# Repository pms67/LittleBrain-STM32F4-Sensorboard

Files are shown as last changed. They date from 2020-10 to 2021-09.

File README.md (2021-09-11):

# LittleBrain-STM32F4-Sensorboard
STM32F4-based PCB interfacing with a variety of sensors.

- Learn how to design your own STM32-based PCB ([https://youtu.be/x_5rYfAyqq0](https://youtu.be/x_5rYfAyqq0))!
- Learn how to write firmware for the STM32 microcontroller ([https://youtu.be/C7-8nUU6e3E](https://youtu.be/C7-8nUU6e3E))!

You can order this board (incl. SMT assembly) at [https://www.jlcpcb.com/RPH](https://www.jlcpcb.com/RPH). Gerber and assembly files are in the relevant repo folders.

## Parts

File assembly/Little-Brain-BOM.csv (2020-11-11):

Comment | Designator | Footprint | LCSC
10u | C100,C102,C103 | Capacitor_SMD:C_1206_3216Metric | C13585
10n | C101 | Capacitor_SMD:C_0603_1608Metric | C57112
4u7 | C200 | Capacitor_SMD:C_0603_1608Metric | C19666
1u | C206 | Capacitor_SMD:C_0402_1005Metric | C52923
10n | C207 | Capacitor_SMD:C_0402_1005Metric | C15195
2u2 | C208,C209 | Capacitor_SMD:C_0603_1608Metric | C23630
12p | C210,C211 | Capacitor_SMD:C_0402_1005Metric | C1547
100n | C201,C202,C203,C204,C205,C212,C213,C300,C301,C302,C303,C400 | Capacitor_SMD:C_0402_1005Metric | C1525
B5819W | D100,D101 | Diode_SMD:D_SOD-123 | C8598
GREEN | D102 | LED_SMD:LED_0603_1608Metric | C72043
RED | D200 | LED_SMD:LED_0603_1608Metric | C2286
19-237/R6GHBHC-A01/2T | D201 | RGB_LED:19-237-R6GHBHC-A01-2T | C60105
250mA | F100 | Fuse:Fuse_1206_3216Metric | C70068
600 @ 600 MHz | FB100,FB200 | Inductor_SMD:L_0805_2012Metric | C1017
10u | L101 | Inductor_SMD:L_Sunlord_MWSA0518_5.4x5.2mm | C139506
AO3401A | Q100 | Package_TO_SOT_SMD:SOT-23 | C15127
100k | R100 | Resistor_SMD:R_0603_1608Metric | C25803
68k | R101 | Resistor_SMD:R_0603_1608Metric | C23231
47k | R102 | Resistor_SMD:R_0603_1608Metric | C25819
15k | R103 | Resistor_SMD:R_0603_1608Metric | C22809
270 | R104 | Resistor_SMD:R_0603_1608Metric | C22966
1k5 | R105 | Resistor_SMD:R_0603_1608Metric | C22843
47 | R200 | Resistor_SMD:R_0402_1005Metric | C25118
1k | R202 | Resistor_SMD:R_0603_1608Metric | C21190
2k2 | R204,R205 | Resistor_SMD:R_0402_1005Metric | C25879
1k | R206,R207,R208 | Resistor_SMD:R_0402_1005Metric | C11702
10k | R201,R203,R209,R210 | Resistor_SMD:R_0402_1005Metric | C25744
22 | R400,R401,R402,R403,R404,R405,R406,R407,R408,R409,R410,R411,R412,R413,R414,R415 | Resistor_SMD:R_0402_1005Metric | C25092
MP2359DJ-LF-Z | U100 | Package_TO_SOT_SMD:SOT-23-6 | C14259
STM32F405RGT6 | U200 | Package_QFP:LQFP-64_10x10mm_P0.5mm | C15742
W25N01GVZEIG | U201 | WinbondFlash:W25N01GVZEIG | C88868
BMP280 | U300 | Package_LGA:Bosch_LGA-8_2x2.5mm_P0.65mm_ClockwisePinNumbering | C233787
BMI088 | U301 | BMI088:BMI088 | C194919
16MHz | Y200 | Crystal:Crystal_SMD_3225-4Pin_3.2x2.5mm | C13738

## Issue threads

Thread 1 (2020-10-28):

Gerber

nbgsmk, 2020-10-28:
Hello friend!
I found your youtube video on stm32 and I thought, let's give it a try! I also wanted to see how it looks in jlcpcb's ordering tool, and to perfect the process, as I am not experienced with pcb fabs. But after uploading gerber files to jlcpcb (I used the provided .rar), the board dimensions are not detected (both fields are empty) and there is no board-preview, as usual. Therefore, the option of their smt assembly is not enabled. Do you know what could be the issue? Thanks!

pms67, 2020-10-28:
Hey there,
That's strange - I just tried uploading the files again myself and everything appears as it should.

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

Maybe some sort of browser issue?

nbgsmk, 2020-10-28:
Hello again!
You're right! Somehow. :)  Ofcourse, I tried twice in the morning, and twice again this evening. And this time it works. But it's the same browser as before. So I'm thinking maybe because I restarted Firefox due to update, or it was some issue on their site. No big deal...actually I learned it is worth waiting and trying, eg. on the following day. Thanks for your quick reply! You can close the issue.
Zoran

Closed 2020-11-07.

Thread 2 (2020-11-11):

W25N01 Spi Nand Flash

MrMehdi, 2020-11-11:
Hi bro
thnx for shareing your nice project.
please start working on w25n01 driver and file system.
that's very nice chip for storage big data
i have some problem for implement a file system like rl-flashfs for this chip.
i wrote a raw low-lever driver for this chip , if you need tell me for sharing to you
i waiting on you to complete this part of your project!
i hope you start very soon
thnx bro.

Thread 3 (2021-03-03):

MP2359 now end of life at JLCPCB

m1geo, 2021-03-03:
Just to let you know that the MP2359DJ-LF-Z is no longer stocked at JLCPCB or LCSC.
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

pms67, 2021-03-12:
Hi there, Thanks - I'm making an updated version of this board with different components. Will make a new video, once I have it in my hands. :)

Closed 2021-03-12.

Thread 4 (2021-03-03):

[Question] Parts designation numbers schema

bennymeg, 2021-03-03:
Hi,
I see you have assign a unique range of numbers for parts designators to each schematic page.
I assume the reason behind it is that it would be easy to understand to each function of the board each component relate to by simply looking at the silk screen. Nice trick!

 - Is that a common practice to do so? can please explain a bit about it?
 - Can you please explain how you did it in KiCad?

Thanks.

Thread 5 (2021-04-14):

U100/U200 no longer known to JLCPCB?

rpbgit, 2021-04-14:
Hi Phil,
wonderful vids on your youtube channel.  Really like your approach from pencil to practice and actual implementations.   particularly the filter/dsp stuff (new to me).   recently retired engineer and a couple of colleagues looking to simulate the brain cells again.  Just turned my first KiCAD boards (simple stuff) for a club built project to learn that.

trying to order some littebrain PCBs ordering from JLCPCB as you have noted in the vids.  However, U100/U100 are no longer known to JLCPCB.  any way to readily correct this?   Would like to follow along with your vids using the LB as the devboard as closely as possible.

Really like the STM32 stuff and recently ordered a STM32H743 Nucleo-144 board but haven't yet gotten the dev environment setup.   If the solution to ordering LittleBrain is longer term, we will probably just go with ordering some sort of BL088 module and get it working with a Nucleo-board.

any suggestions?

rpbgit, 2021-04-16:
ooops U200 and U100

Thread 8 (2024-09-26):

SPI NSS for gyro and accelerometer being pulled low at the same time.

jisang1213, 2024-09-26:
I've faced an issue with gyro and accelerometer CS pins being pulled low simultaneously, making the retrieved data contain garbage values once a while (about every 1~2 seconds). There needs to be a mechanism to prevent this like using while() to wait for its turn to read.
```
void HAL_GPIO_EXTI_Callback(uint16_t GPIO_Pin) {
	if (GPIO_Pin == INT_ACC_Pin) {
                while(imu.readingGyr);
                BMI088_ReadAccelerometerDMA(&imu);

	} else if (GPIO_Pin == INT_GYR_Pin) {
                while(imu.readingAcc);
                BMI088_ReadGyroscopeDMA(&imu);
	}
}
```
and in the BMI088.c file the imu.readingGyr and imu.readingAcc flags should be set before pulling the CS low (and unset after pulling CS to high) to prevent race condition.

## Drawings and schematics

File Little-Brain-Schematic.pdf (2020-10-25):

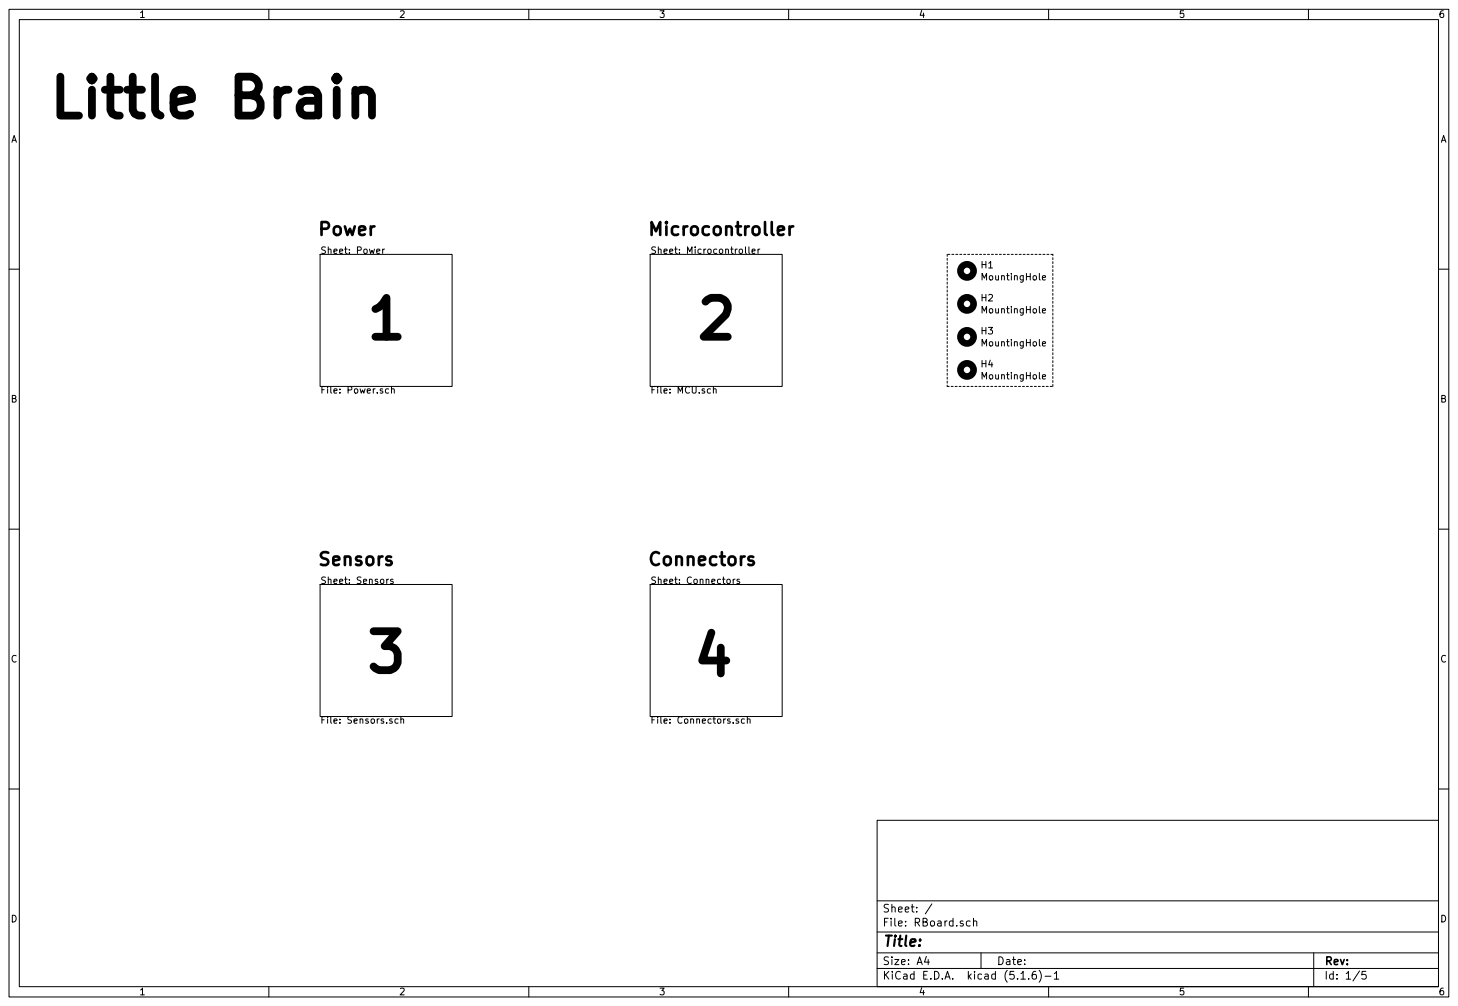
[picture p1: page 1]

Id: 1/5 Title: File: RBoard.sch Sheet: /

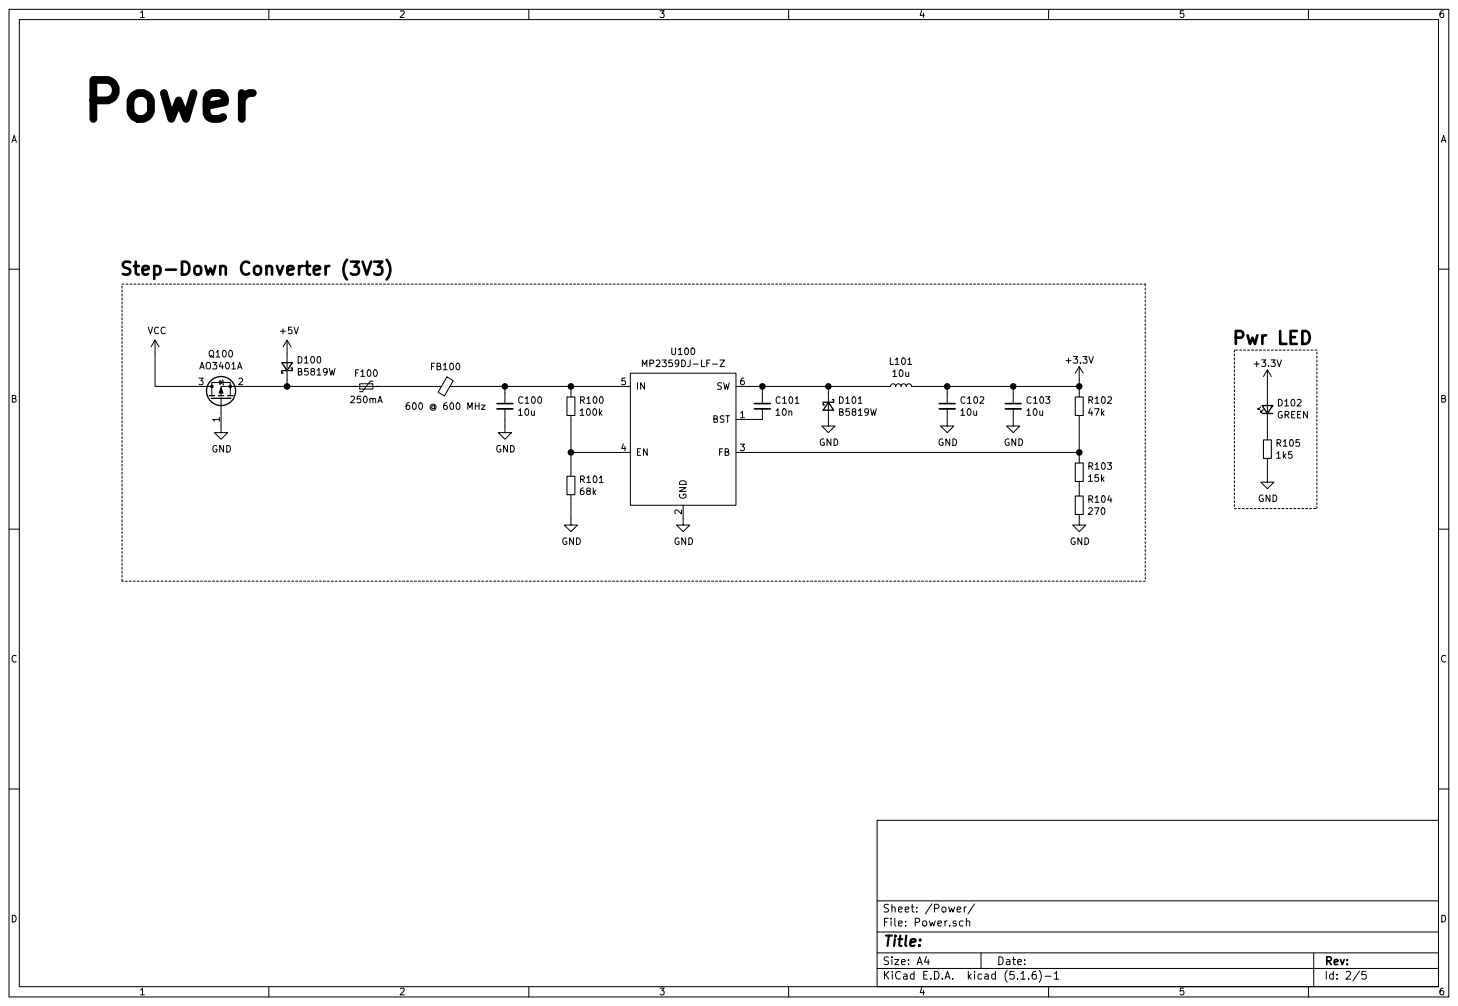
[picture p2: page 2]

Id: 2/5 Title: File: Power.sch Sheet: /Power/

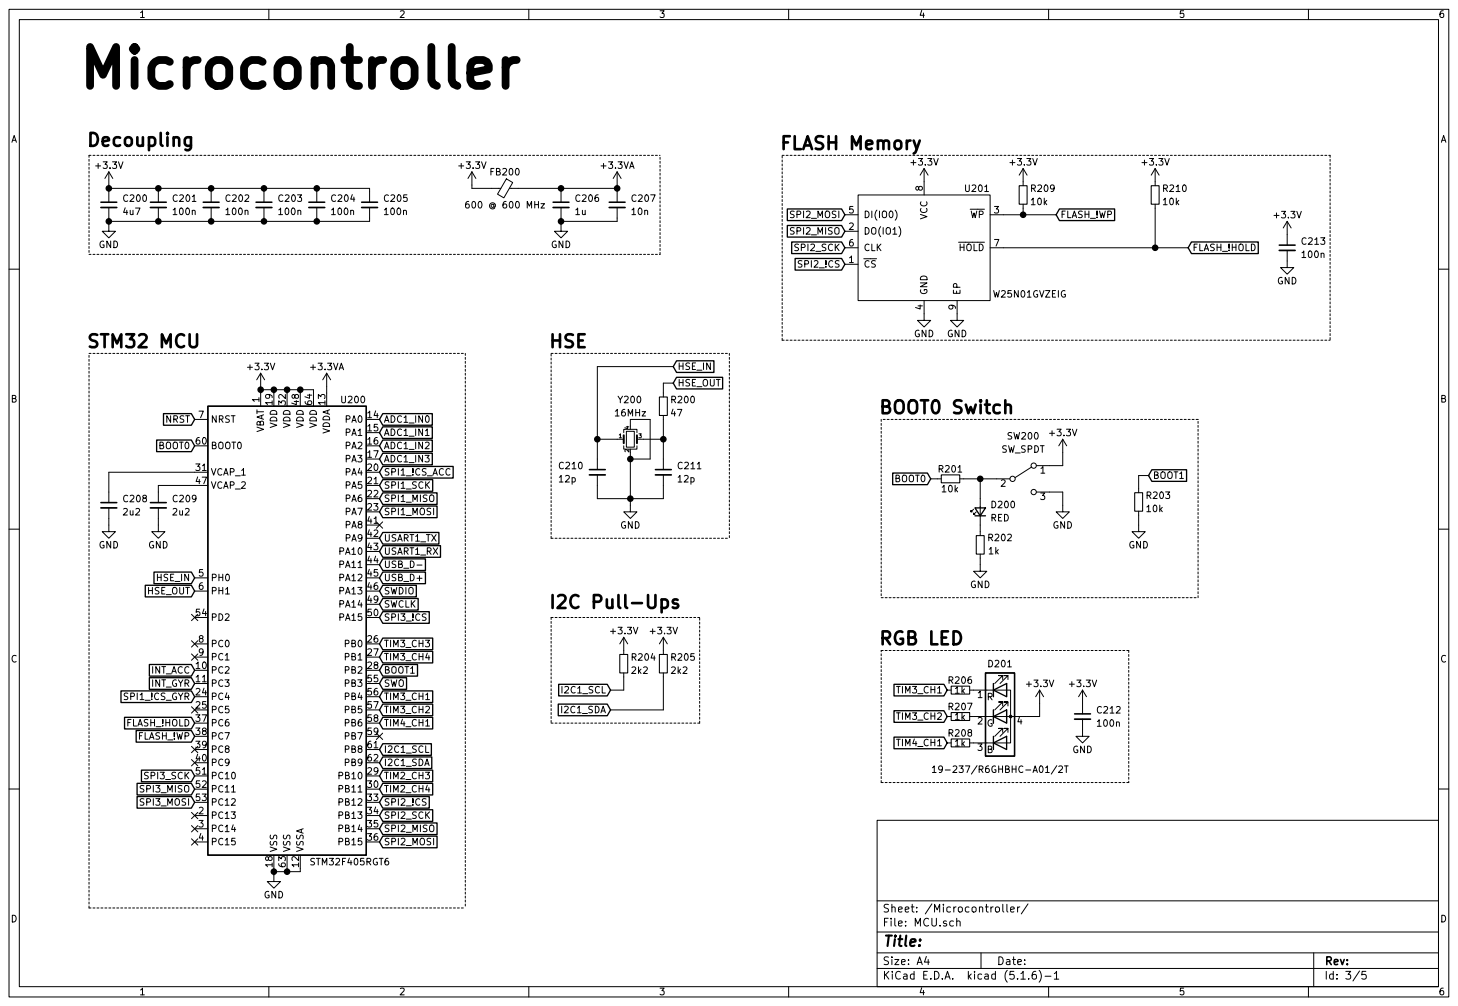
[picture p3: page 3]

4 DI(IO0) 5 CLK 6 HOLD 7 VCC

1 VCAP_1 31 VCAP_2 47 VDD 19 VDD 32 VDD 48 VDD 64 VDDA 13 VSS 18 VSS 63 VSSA 12 U200 STM32F405RGT6

Id: 3/5 Title: File: MCU.sch Sheet: /Microcontroller/ GND

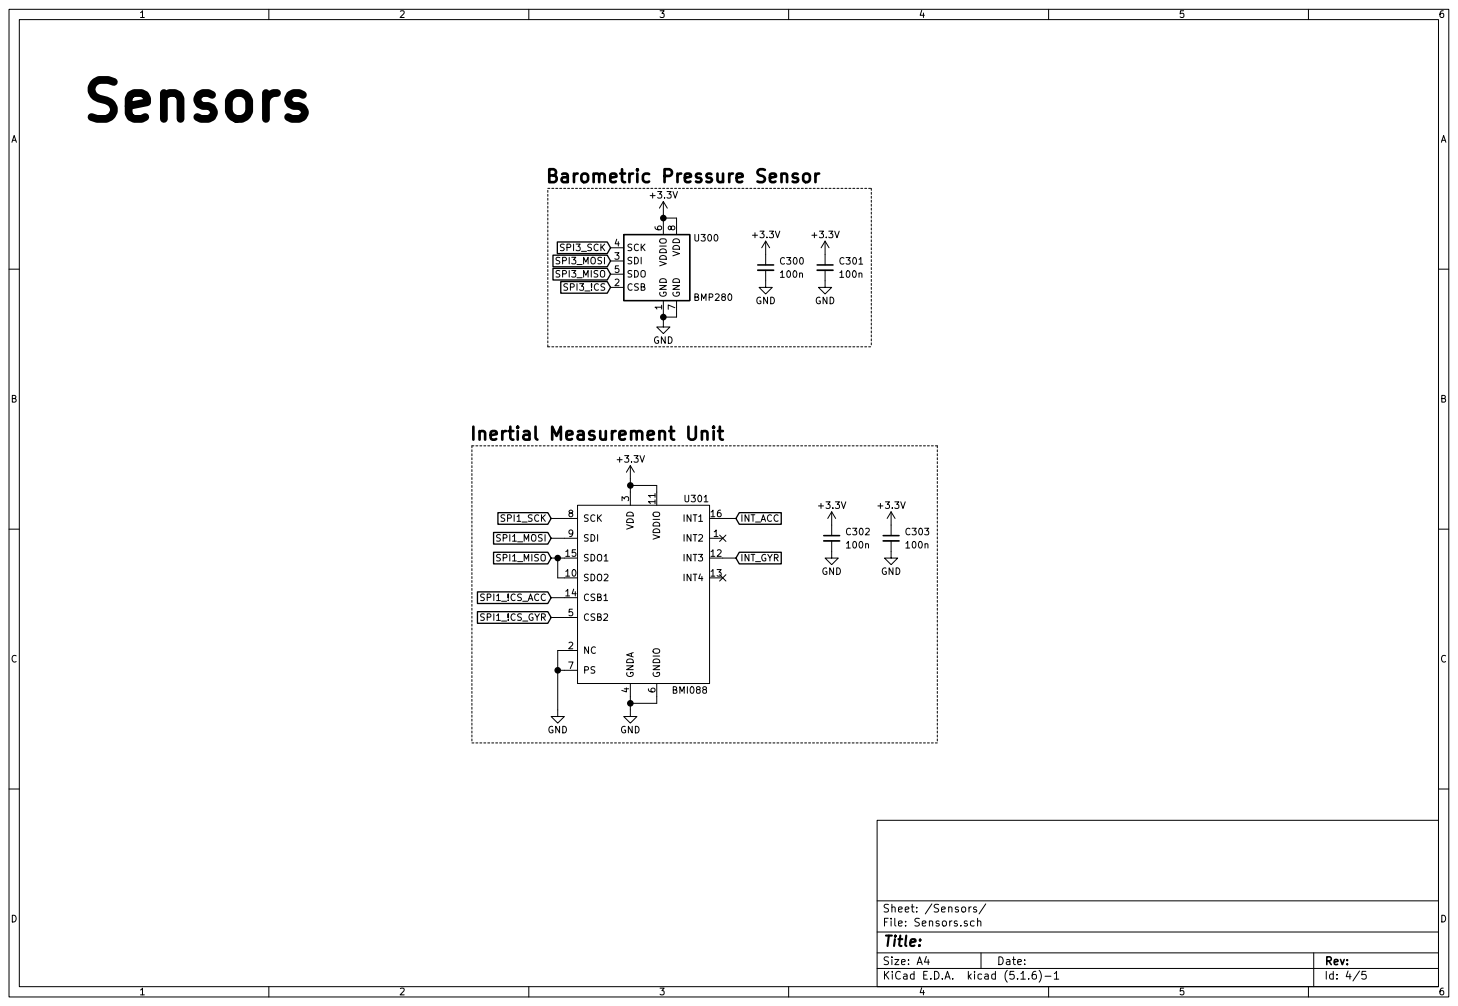
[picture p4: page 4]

1 CSB 2 SDI 3 SCK 4 SDO 5 VDDIO

6 PS 7 SCK 8 SDI 9 U301 BMI088 GND

Id: 4/5 Title: File: Sensors.sch Sheet: /Sensors/ C303

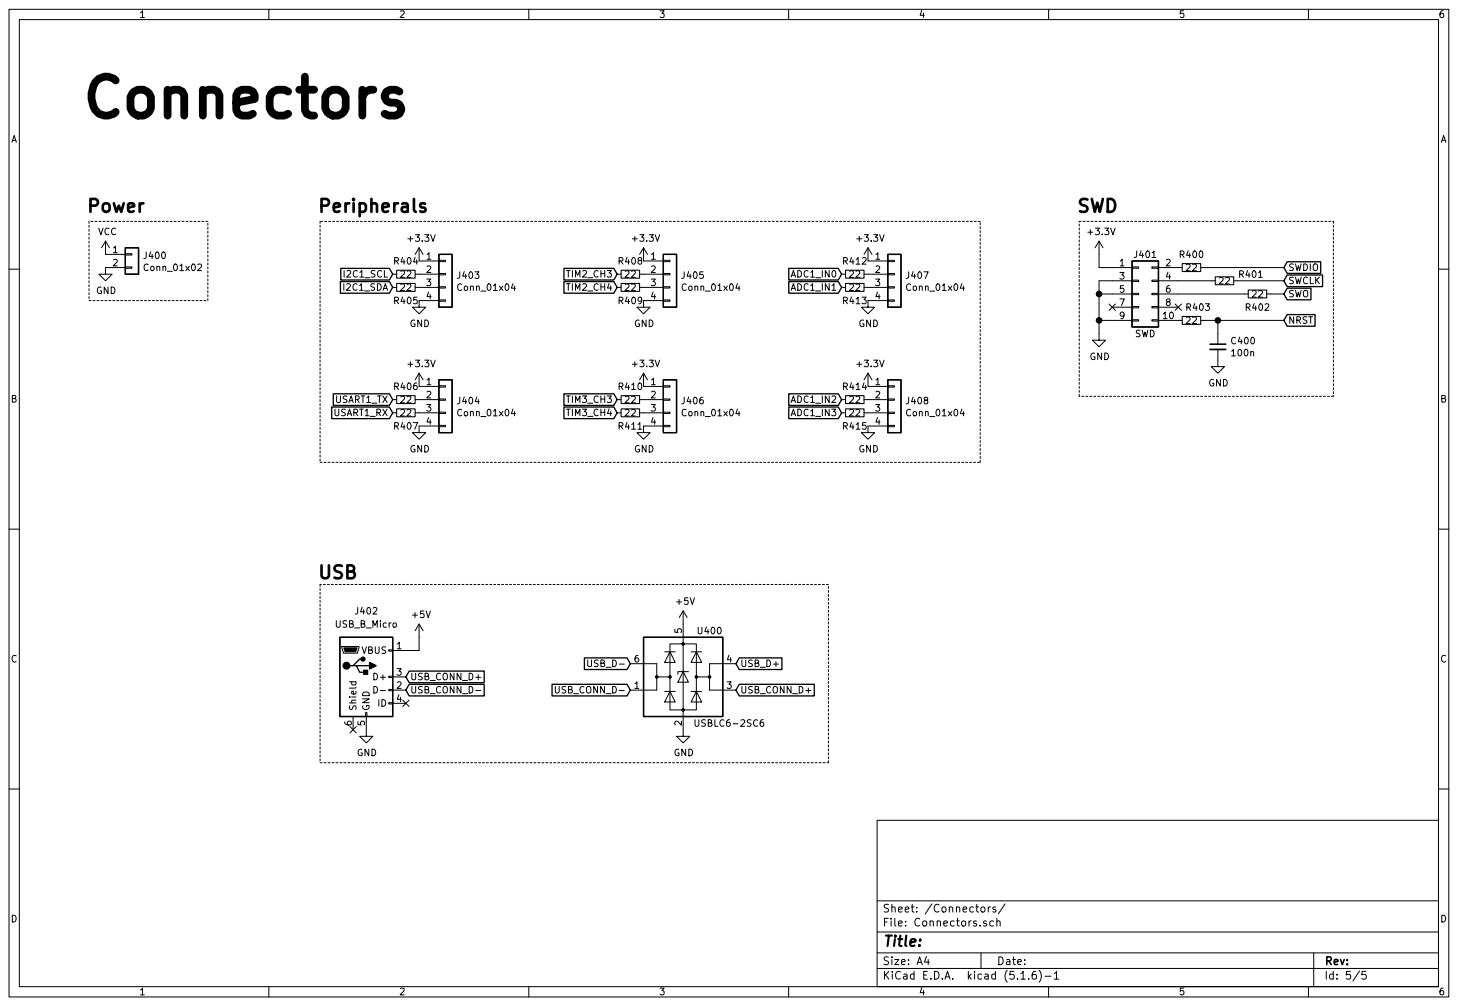
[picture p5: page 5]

Id: 5/5 Title: File: Connectors.sch Sheet: /Connectors/

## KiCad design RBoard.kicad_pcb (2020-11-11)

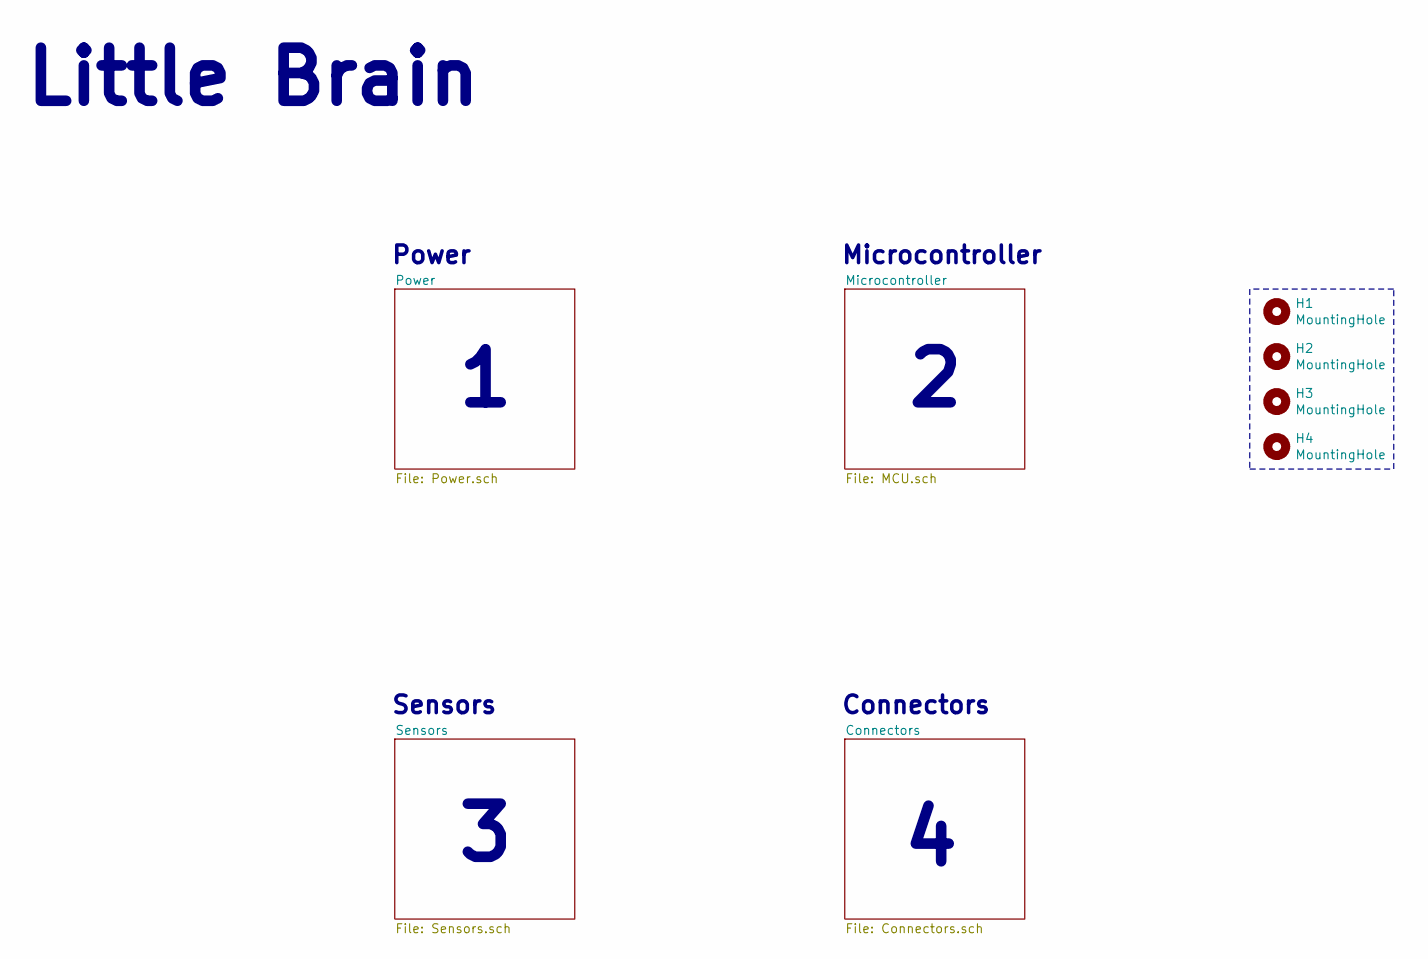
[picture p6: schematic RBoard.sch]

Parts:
H1, H2, H3, H4: MountingHole; MountingHole_3.2mm_M3

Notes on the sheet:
Little Brain
Power
Microcontroller
Sensors
Connectors

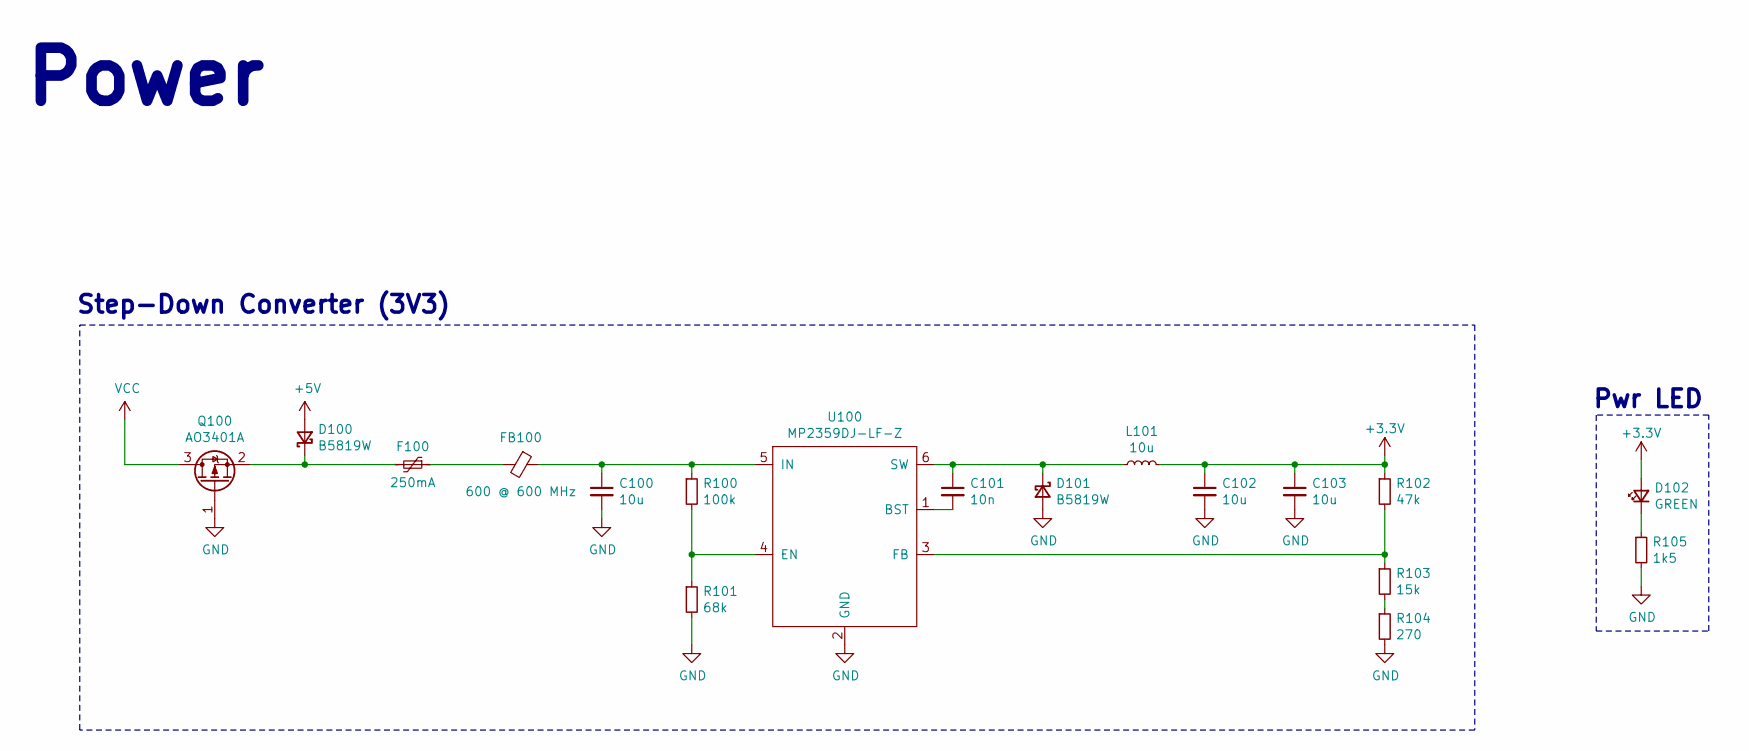
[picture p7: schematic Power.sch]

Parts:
C100, C102, C103: 10u; C_1206_3216Metric; LCSC Part # C13585
C101: 10n; C_0603_1608Metric; LCSC Part # C57112
D100, D101: B5819W; D_SOD-123; LCSC Part # C8598
D102: GREEN; LED_0603_1608Metric; LCSC Part # C72043
F100: 250mA; Fuse_1206_3216Metric; LCSC Part # C70068
FB100: 600 @ 600 MHz; L_0805_2012Metric; LCSC Part # C1017
L101: 10u; L_Sunlord_MWSA0518_5.4x5.2mm; LCSC Part # C139506
Q100: AO3401A; SOT-23; LCSC Part # C15127
R100: 100k; R_0603_1608Metric; LCSC Part # C25803
R101: 68k; R_0603_1608Metric; LCSC Part # C23231
R102: 47k; R_0603_1608Metric; LCSC Part # C25819
R103: 15k; R_0603_1608Metric; LCSC Part # C22809
R104: 270; R_0603_1608Metric; LCSC Part # C22966
R105: 1k5; R_0603_1608Metric; LCSC Part # C22843
U100: MP2359DJ-LF-Z; SOT-23-6; LCSC Part # C14259

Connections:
+3V3: C102.1, C103.1, D102.2 (A), L101.2, R102.1; also elsewhere on the board
+5V: D100.2 (A); also elsewhere on the board
GND: C100.2, C102.2, C103.2, D101.2 (A), Q100.1 (G), R101.2, R104.2, R105.2, U100.2 (GND); also elsewhere on the board
unnamed: C100.1, FB100.1, R100.1, U100.5 (IN)
unnamed: C101.1, D101.1 (K), L101.1, U100.6 (SW)
unnamed: C101.2, U100.1 (BST)
unnamed: D100.1 (K), F100.2, Q100.2 (S)
unnamed: D102.1 (K), R105.1
unnamed: F100.1, FB100.2
unnamed: R100.2, R101.1, U100.4 (EN)
unnamed: R102.2, R103.1, U100.3 (FB)
unnamed: R103.2, R104.1
VCC: Q100.3 (D); also elsewhere on the board

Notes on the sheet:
Power
Step-Down Converter (3V3)
Pwr LED

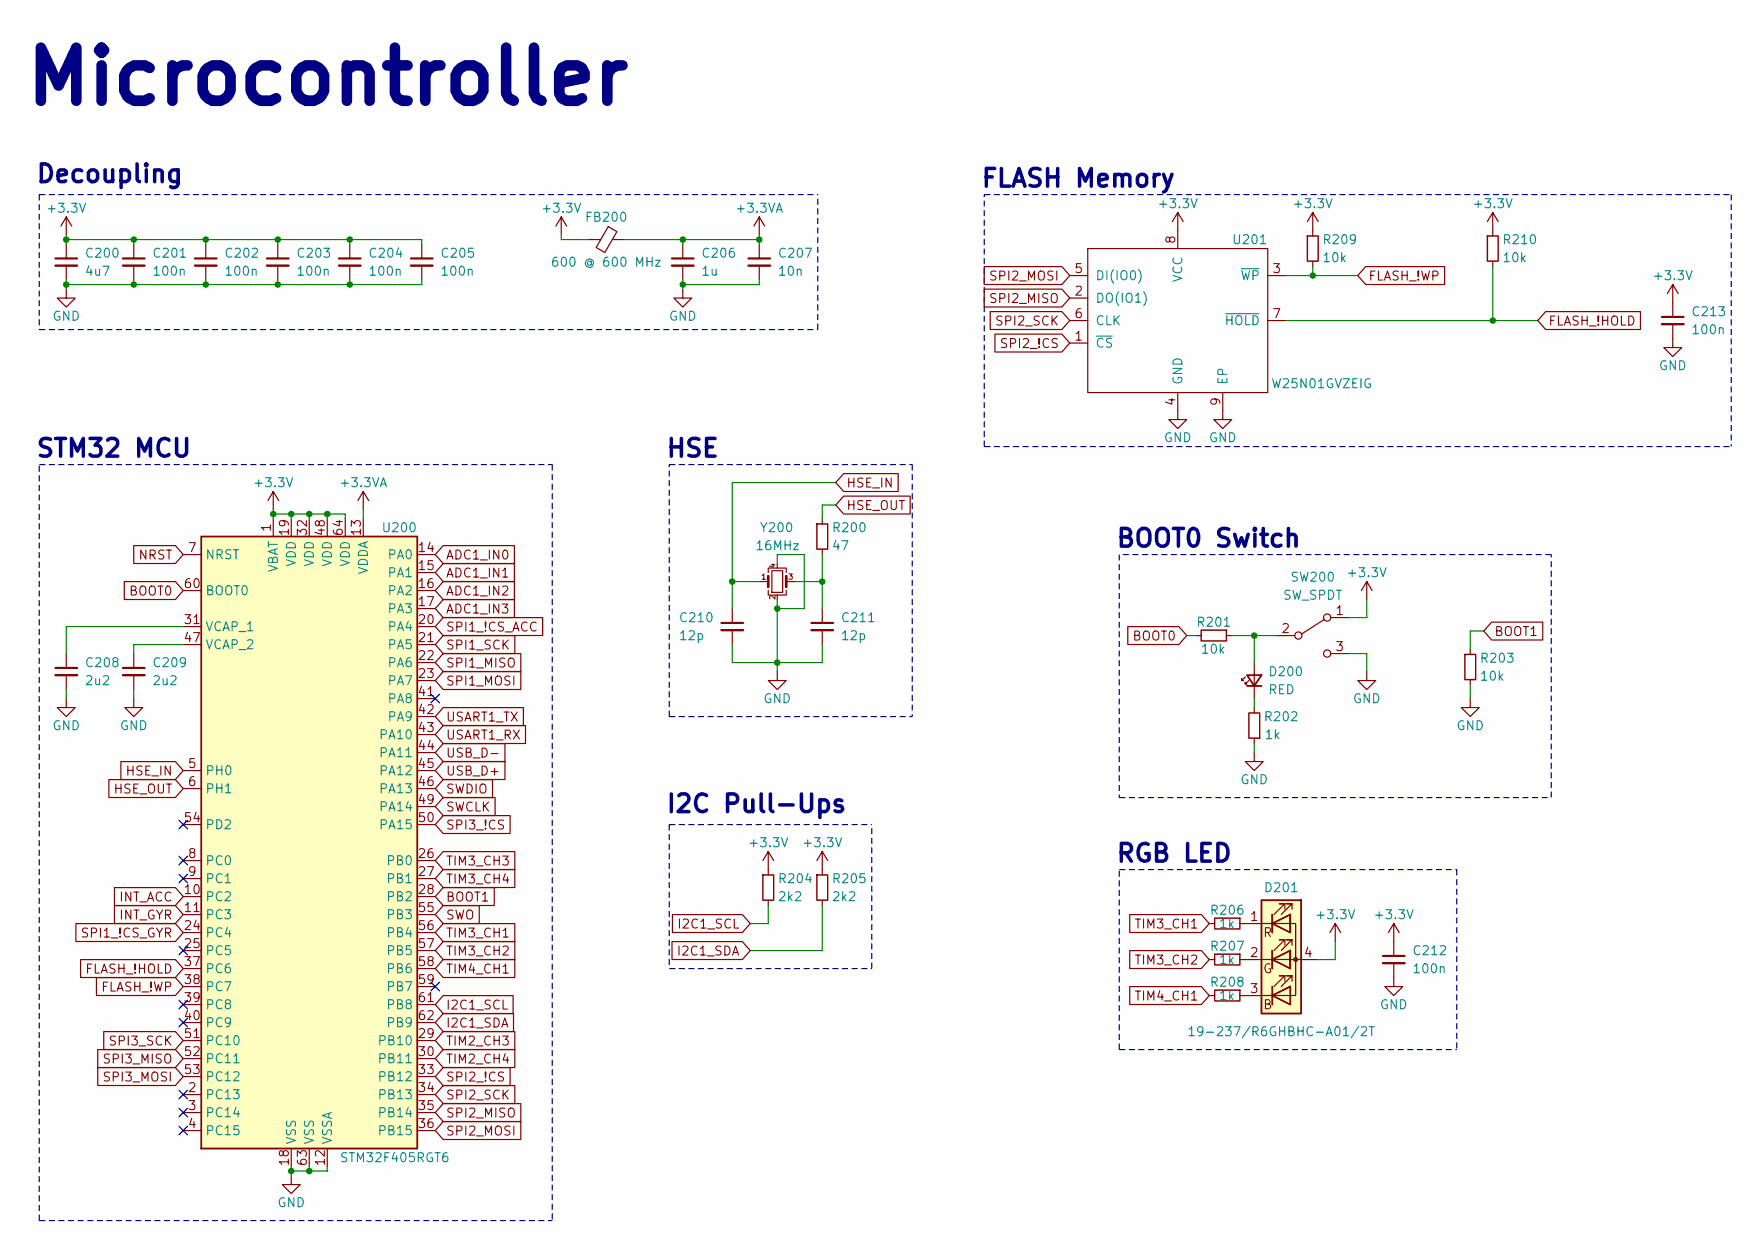
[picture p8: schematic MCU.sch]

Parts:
C200: 4u7; C_0603_1608Metric; LCSC Part # C19666
C201, C202, C203, C204, C205, C212, C213: 100n; C_0402_1005Metric; LCSC Part # C1525
C206: 1u; C_0402_1005Metric; LCSC Part # C52923
C207: 10n; C_0402_1005Metric; LCSC Part # C15195
C208, C209: 2u2; C_0603_1608Metric; LCSC Part # C23630
C210, C211: 12p; C_0402_1005Metric; LCSC Part # C1547
D200: RED; LED_0603_1608Metric; LCSC Part # C2286
D201: 19-237/R6GHBHC-A01/2T; 19-237-R6GHBHC-A01-2T; LCSC Part # C60105
FB200: 600 @ 600 MHz; L_0805_2012Metric; LCSC Part # C1017
R200: 47; R_0402_1005Metric; LCSC Part # C25118
R201, R203, R209, R210: 10k; R_0402_1005Metric; LCSC Part # C25744
R202: 1k; R_0603_1608Metric; LCSC Part # C21190
R204, R205: 2k2; R_0402_1005Metric; LCSC Part # C25879
R206, R207, R208: 1k; R_0402_1005Metric; LCSC Part # C11702
SW200: SW_SPDT; SW_SPDT_PCM12
U200: STM32F405RGT6; LQFP-64_10x10mm_P0.5mm; LCSC Part # C15742
U201: W25N01GVZEIG; LCSC Part # C88868
Y200: 16MHz; Crystal_SMD_3225-4Pin_3.2x2.5mm; LCSC Part # C13738

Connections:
+3.3VA: C206.1, C207.1, FB200.1, U200.13 (VDDA)
+3V3: C200.1, C201.1, C202.1, C203.1, C204.1, C205.1, C212.1, C213.1, D201.4 (A), FB200.2, R204.1, R205.1, R209.1, R210.1, SW200.1 (A), U200.1 (VBAT), U200.19 (VDD), U200.32 (VDD), U200.48 (VDD), U200.64 (VDD), U201.8 (VCC); also elsewhere on the board
ADC1_IN0: U200.14 (PA0); also elsewhere on the board
ADC1_IN1: U200.15 (PA1); also elsewhere on the board
ADC1_IN2: U200.16 (PA2); also elsewhere on the board
ADC1_IN3: U200.17 (PA3); also elsewhere on the board
BOOT0: R201.2, U200.60 (BOOT0)
BOOT1: R203.1, U200.28 (PB2)
FLASH_!HOLD: R210.2, U200.37 (PC6), U201.7 (~HOLD)
FLASH_!WP: R209.2, U200.38 (PC7), U201.3 (~WP)
GND: C200.2, C201.2, C202.2, C203.2, C204.2, C205.2, C206.2, C207.2, C208.2, C209.2, C210.2, C211.2, C212.2, C213.2, R202.1, R203.2, SW200.3 (C), U200.12 (VSSA), U200.18 (VSS), U200.63 (VSS), U201.4 (GND), U201.9 (EP), Y200.2, Y200.4; also elsewhere on the board
HSE_IN: C210.1, U200.5 (PH0), Y200.1
HSE_OUT: R200.1, U200.6 (PH1)
I2C1_SCL: R204.2, U200.61 (PB8); also elsewhere on the board
I2C1_SDA: R205.2, U200.62 (PB9); also elsewhere on the board
INT_ACC: U200.10 (PC2); also elsewhere on the board
INT_GYR: U200.11 (PC3); also elsewhere on the board
NRST: U200.7 (NRST); also elsewhere on the board
unnamed: C208.1, U200.31 (VCAP_1)
unnamed: C209.1, U200.47 (VCAP_2)
unnamed: C211.1, R200.2, Y200.3
unnamed: D200.1 (K), R202.2
unnamed: D200.2 (A), R201.1, SW200.2 (B)
unnamed: D201.1 (RK), R206.1
unnamed: D201.2 (GK), R207.1
unnamed: D201.3 (BK), R208.1
SPI1_!CS_ACC: U200.20 (PA4); also elsewhere on the board
SPI1_!CS_GYR: U200.24 (PC4); also elsewhere on the board
SPI1_MISO: U200.22 (PA6); also elsewhere on the board
SPI1_MOSI: U200.23 (PA7); also elsewhere on the board
SPI1_SCK: U200.21 (PA5); also elsewhere on the board
SPI2_!CS: U200.33 (PB12), U201.1 (~CS)
SPI2_MISO: U200.35 (PB14), U201.2 (DO(IO1))
SPI2_MOSI: U200.36 (PB15), U201.5 (DI(IO0))
SPI2_SCK: U200.34 (PB13), U201.6 (CLK)
SPI3_!CS: U200.50 (PA15); also elsewhere on the board
SPI3_MISO: U200.52 (PC11); also elsewhere on the board
SPI3_MOSI: U200.53 (PC12); also elsewhere on the board
SPI3_SCK: U200.51 (PC10); also elsewhere on the board
SWCLK: U200.49 (PA14); also elsewhere on the board
SWDIO: U200.46 (PA13); also elsewhere on the board
SWO: U200.55 (PB3); also elsewhere on the board
TIM2_CH3: U200.29 (PB10); also elsewhere on the board
TIM2_CH4: U200.30 (PB11); also elsewhere on the board
TIM3_CH1: R206.2, U200.56 (PB4)
TIM3_CH2: R207.2, U200.57 (PB5)
TIM3_CH3: U200.26 (PB0); also elsewhere on the board
TIM3_CH4: U200.27 (PB1); also elsewhere on the board
TIM4_CH1: R208.2, U200.58 (PB6)
USART1_RX: U200.43 (PA10); also elsewhere on the board
USART1_TX: U200.42 (PA9); also elsewhere on the board
USB_D+: U200.45 (PA12); also elsewhere on the board
USB_D-: U200.44 (PA11); also elsewhere on the board

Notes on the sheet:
Microcontroller
STM32 MCU
Decoupling
HSE
FLASH Memory
BOOT0 Switch
RGB LED
I2C Pull-Ups

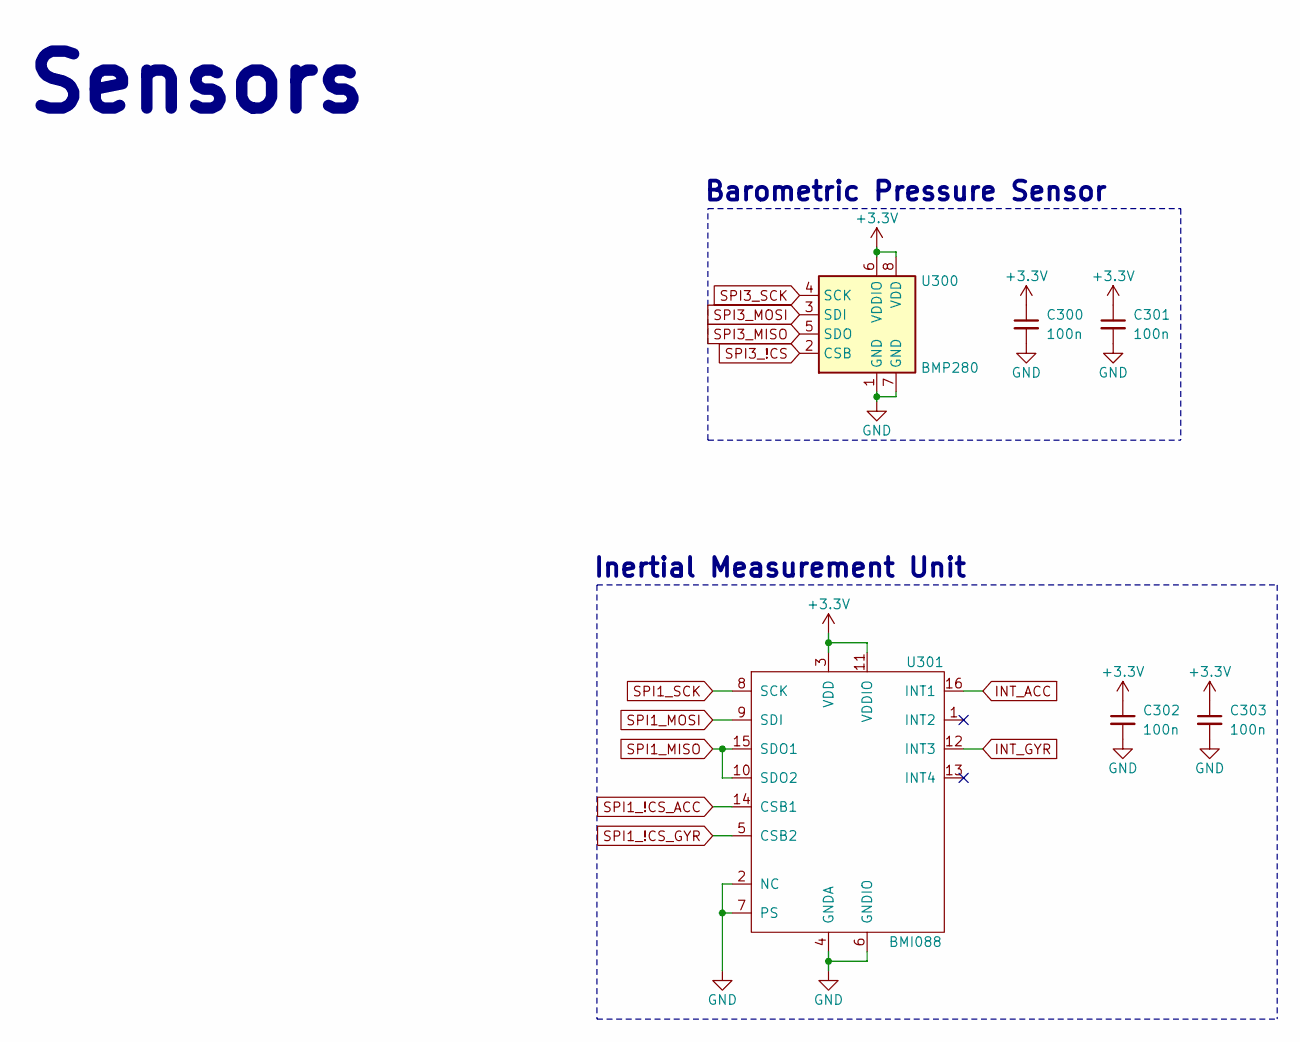
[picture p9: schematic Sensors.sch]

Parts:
C300, C301, C302, C303: 100n; C_0402_1005Metric; LCSC Part # C1525
U300: BMP280; Bosch_LGA-8_2x2.5mm_P0.65mm_ClockwisePinNumbering; LCSC Part # C233787
U301: BMI088; LCSC Part # C194919

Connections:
+3V3: C300.1, C301.1, C302.1, C303.1, U300.6 (VDDIO), U300.8 (VDD), U301.3 (VDD), U301.11 (VDDIO); also elsewhere on the board
GND: C300.2, C301.2, C302.2, C303.2, U300.1 (GND), U300.7 (GND), U301.2 (NC), U301.4 (GNDA), U301.6 (GNDIO), U301.7 (PS); also elsewhere on the board
INT_ACC: U301.16 (INT1); also elsewhere on the board
INT_GYR: U301.12 (INT3); also elsewhere on the board
SPI1_!CS_ACC: U301.14 (CSB1); also elsewhere on the board
SPI1_!CS_GYR: U301.5 (CSB2); also elsewhere on the board
SPI1_MISO: U301.10 (SDO2), U301.15 (SDO1); also elsewhere on the board
SPI1_MOSI: U301.9 (SDI); also elsewhere on the board
SPI1_SCK: U301.8 (SCK); also elsewhere on the board
SPI3_!CS: U300.2 (CSB); also elsewhere on the board
SPI3_MISO: U300.5 (SDO); also elsewhere on the board
SPI3_MOSI: U300.3 (SDI); also elsewhere on the board
SPI3_SCK: U300.4 (SCK); also elsewhere on the board

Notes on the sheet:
Sensors
Barometric Pressure Sensor
Inertial Measurement Unit

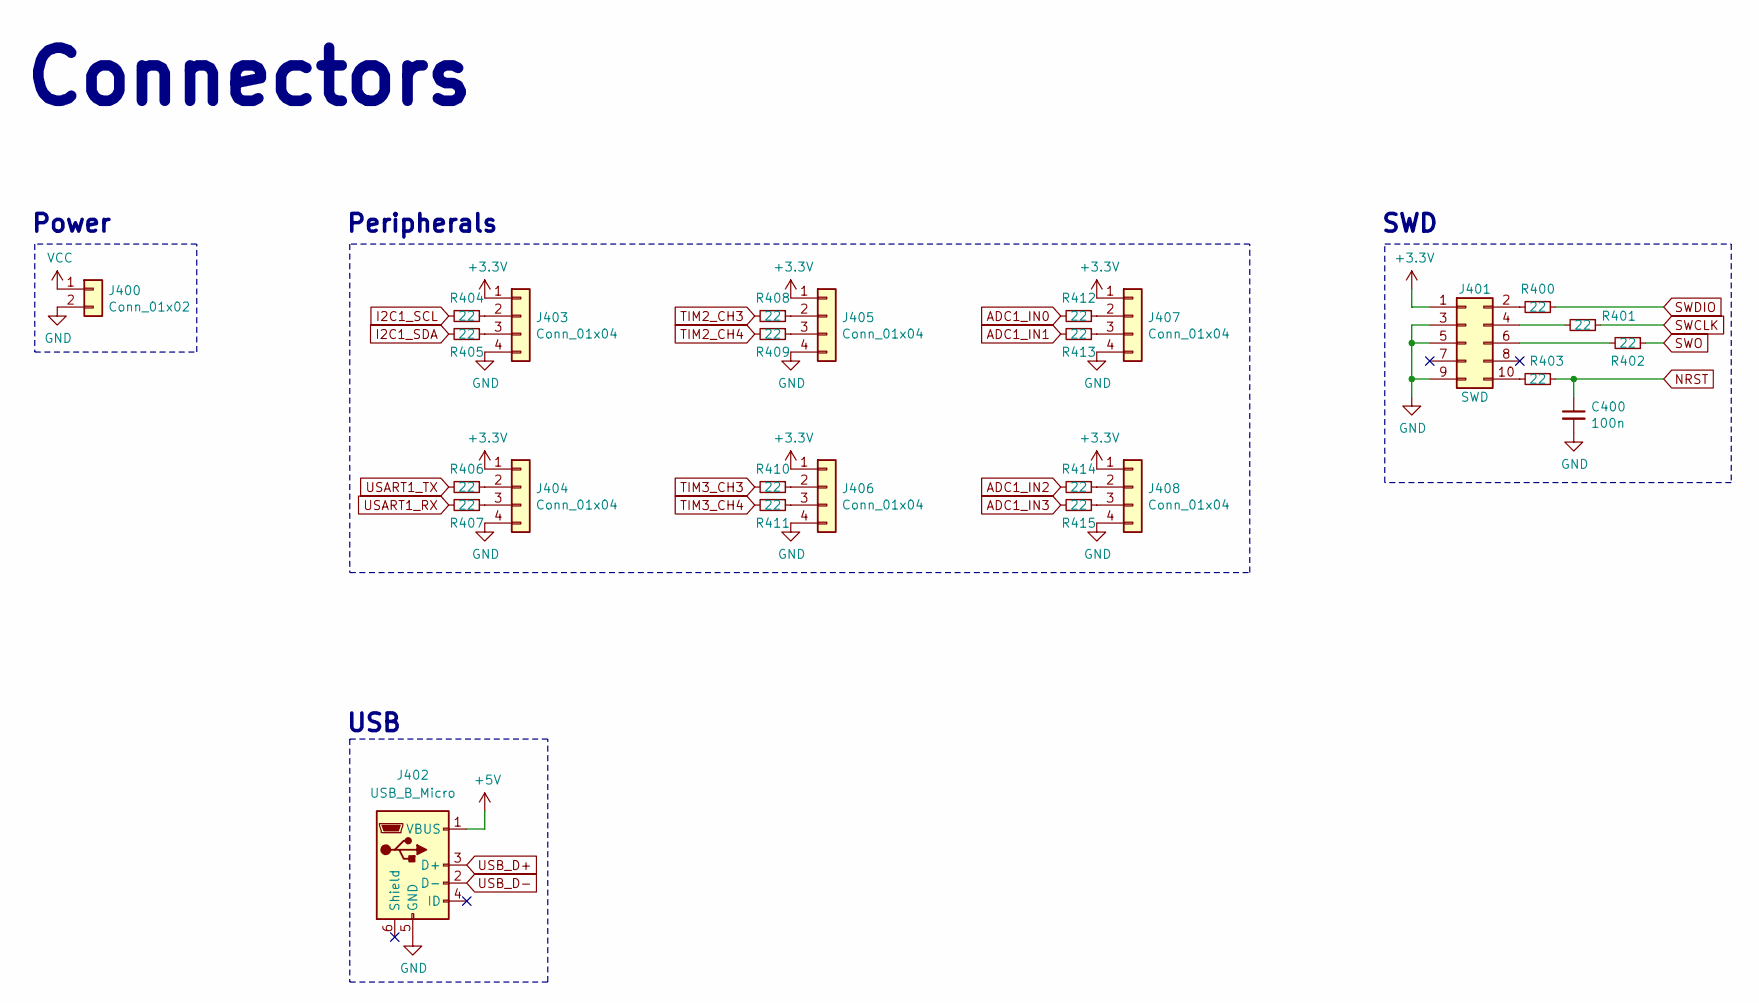
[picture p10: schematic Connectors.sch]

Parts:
C400: 100n; C_0402_1005Metric; LCSC Part # C1525
J400: Conn_01x02; Molex_PicoBlade_53048-0210_1x02_P1.25mm_Horizontal
J401: SWD; PinHeader_2x05_P1.27mm_Vertical_SMD
J402: USB_B_Micro; USB_Micro-B_Wuerth_629105150521
J403, J404, J405, J406, J407, J408: Conn_01x04; Molex_PicoBlade_53048-0410_1x04_P1.25mm_Horizontal
R400, R401, R402, R403, R404, R405, R406, R407, R408, R409, R410, R411, R412, R413, R414, R415: 22; R_0402_1005Metric; LCSC Part # C25092

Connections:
+3V3: J401.1, J403.1, J404.1, J405.1, J406.1, J407.1, J408.1; also elsewhere on the board
+5V: J402.1 (VBUS); also elsewhere on the board
ADC1_IN0: R412.2; also elsewhere on the board
ADC1_IN1: R413.2; also elsewhere on the board
ADC1_IN2: R414.2; also elsewhere on the board
ADC1_IN3: R415.2; also elsewhere on the board
GND: C400.2, J400.2, J401.3, J401.5, J401.9, J402.5 (GND), J403.4, J404.4, J405.4, J406.4, J407.4, J408.4; also elsewhere on the board
I2C1_SCL: R404.2; also elsewhere on the board
I2C1_SDA: R405.2; also elsewhere on the board
NRST: C400.1, R403.1; also elsewhere on the board
unnamed: J401.2, R400.2
unnamed: J401.4, R401.2
unnamed: J401.6, R402.2
unnamed: J401.10, R403.2
unnamed: J403.2, R404.1
unnamed: J403.3, R405.1
unnamed: J404.2, R406.1
unnamed: J404.3, R407.1
unnamed: J405.2, R408.1
unnamed: J405.3, R409.1
unnamed: J406.2, R410.1
unnamed: J406.3, R411.1
unnamed: J407.2, R412.1
unnamed: J407.3, R413.1
unnamed: J408.2, R414.1
unnamed: J408.3, R415.1
SWCLK: R401.1; also elsewhere on the board
SWDIO: R400.1; also elsewhere on the board
SWO: R402.1; also elsewhere on the board
TIM2_CH3: R408.2; also elsewhere on the board
TIM2_CH4: R409.2; also elsewhere on the board
TIM3_CH3: R410.2; also elsewhere on the board
TIM3_CH4: R411.2; also elsewhere on the board
USART1_RX: R407.2; also elsewhere on the board
USART1_TX: R406.2; also elsewhere on the board
USB_D+: J402.3 (D+); also elsewhere on the board
USB_D-: J402.2 (D-); also elsewhere on the board
VCC: J400.1; also elsewhere on the board

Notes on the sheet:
Connectors
USB
Peripherals
Power
SWD

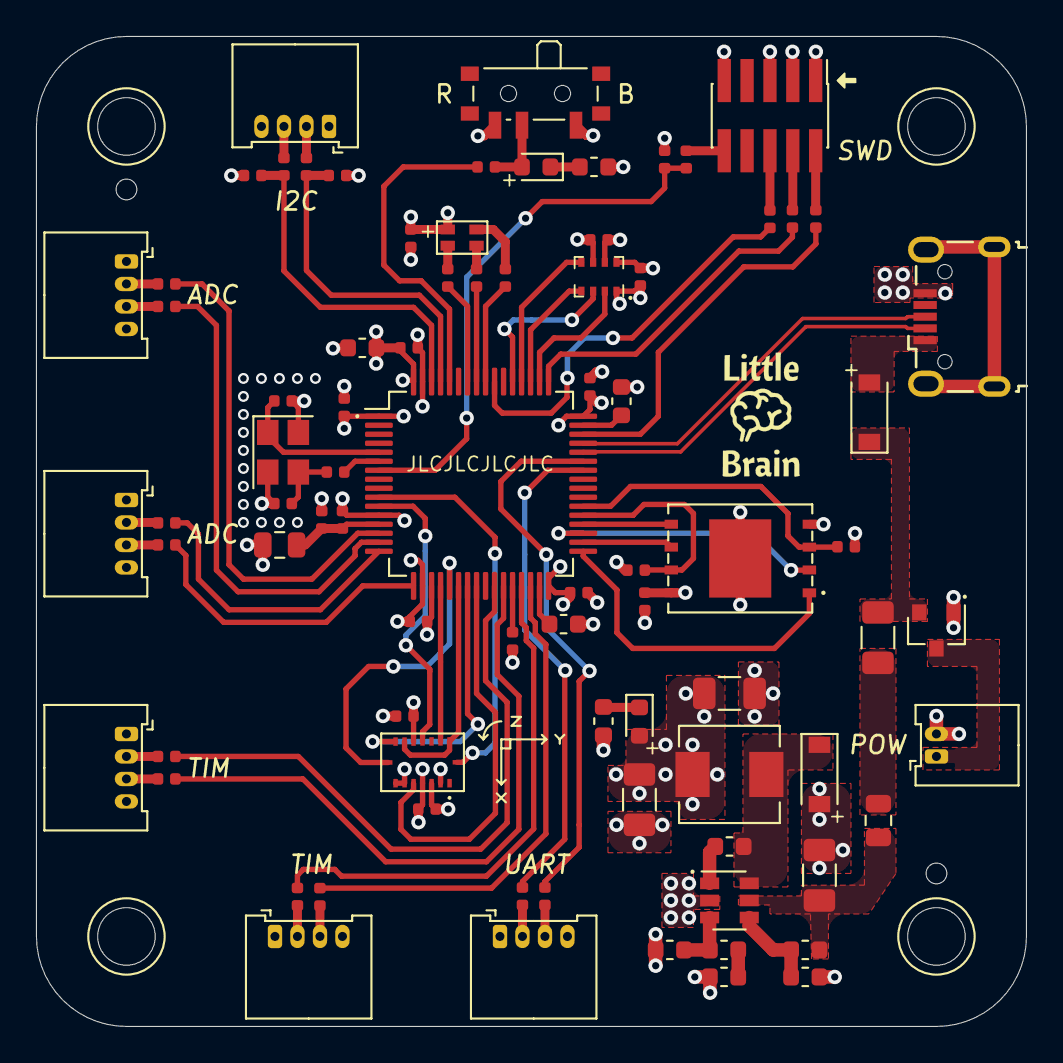
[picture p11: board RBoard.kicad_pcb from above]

Board: 4 copper layers, 55.0 x 55.0 mm, 86 parts (0 on the bottom side), 80 nets.

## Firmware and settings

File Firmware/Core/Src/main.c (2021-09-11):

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

/* Includes ------------------------------------------------------------------*/
#include "main.h"
#include "usb_device.h"

/* USER CODE BEGIN Includes */
#include "usbd_cdc_if.h"
#include <math.h>

#include "BMI088.h"
#include "SPL06.h"

#include "FIRFilter.h"
#include "RCFilter.h"

//#include "EKF.h"
/* USER CODE END Includes */

#define SAMPLE_TIME_MS_USB  20
#define SAMPLE_TIME_MS_BAR  125
#define SAMPLE_TIME_MS_LED  250
#define SAMPLE_TIME_MS_ATT   10

#define COMP_FILT_ALPHA 0.1f
#define RAD_TO_DEG 		57.2957795131f
SPI_HandleTypeDef hspi1;
SPI_HandleTypeDef hspi3;
DMA_HandleTypeDef hdma_spi1_rx;
DMA_HandleTypeDef hdma_spi1_tx;
DMA_HandleTypeDef hdma_spi3_rx;
DMA_HandleTypeDef hdma_spi3_tx;

TIM_HandleTypeDef htim3;
TIM_HandleTypeDef htim4;

/* USER CODE BEGIN PV */
BMI088 imu;
SPL06  bar;

RCFilter lpfAcc[3];
RCFilter lpfGyr[3];

FIRFilter barFilterMovingAverage;

float rollEstimate_rad;
float pitchEstimate_rad;

//EKF ekf;
/* USER CODE END PV */

void SystemClock_Config(void);
static void MX_GPIO_Init(void);
static void MX_DMA_Init(void);
static void MX_SPI1_Init(void);
static void MX_SPI3_Init(void);
static void MX_TIM3_Init(void);
static void MX_TIM4_Init(void);
/* USER CODE BEGIN 0 */
void HAL_SPI_TxRxCpltCallback(SPI_HandleTypeDef *hspi) {

	if (hspi->Instance == SPI1) {

		if (imu.readingAcc) {

			BMI088_ReadAccelerometerDMA_Complete(&imu);

			/* Filter accelerometer data */
		//	RCFilter_Update(&lpfAcc[0], imu.acc_mps2[0]);
		//	RCFilter_Update(&lpfAcc[1], imu.acc_mps2[1]);
		//	RCFilter_Update(&lpfAcc[2], imu.acc_mps2[2]);

		}

		if (imu.readingGyr) {

			BMI088_ReadGyroscopeDMA_Complete(&imu);

			/* Filter gyroscope data */
		//	RCFilter_Update(&lpfGyr[0], imu.gyr_rps[0]);
		//	RCFilter_Update(&lpfGyr[1], imu.gyr_rps[1]);
		//	RCFilter_Update(&lpfGyr[2], imu.gyr_rps[2]);

		}

	} else if (hspi->Instance == SPI3) {

		if (bar.reading) {

			SPL06_ReadDMA_Complete(&bar);

			/* Filter barometer readings using 10-point moving average filter */
			FIRFilter_Update(&barFilterMovingAverage, bar.pressure_Pa);

		}

	}

}

void HAL_GPIO_EXTI_Callback(uint16_t GPIO_Pin) {

	if (GPIO_Pin == INT_ACC_Pin) {

		BMI088_ReadAccelerometerDMA(&imu);

	} else if (GPIO_Pin == INT_GYR_Pin) {

		BMI088_ReadGyroscopeDMA(&imu);

	}

}

void LED_RGB_Init() {

	/* Start RGB LED PWM timers */
	HAL_TIM_PWM_Start(&htim3, TIM_CHANNEL_1);
	HAL_TIM_PWM_Start(&htim3, TIM_CHANNEL_2);
	HAL_TIM_PWM_Start(&htim4, TIM_CHANNEL_1);

}

void LED_RGB_SetIntensity(uint8_t red, uint8_t green, uint8_t blue) {

	htim3.Instance->CCR1 = 100 - red;
	htim3.Instance->CCR2 = 100 - green;
	htim4.Instance->CCR1 = 100 - blue;

}
/* USER CODE END 0 */

/**
  * @brief  The application entry point.
  * @retval int
  */
int main(void)
{
  /* MCU Configuration--------------------------------------------------------*/

  /* Reset of all peripherals, Initializes the Flash interface and the Systick. */
  HAL_Init();

  /* Configure the system clock */
  SystemClock_Config();

  /* Initialize all configured peripherals */
  MX_GPIO_Init();
  MX_DMA_Init();
  MX_SPI1_Init();
  MX_SPI3_Init();
  MX_TIM3_Init();
  MX_TIM4_Init();
  MX_USB_DEVICE_Init();
  /* USER CODE BEGIN 2 */

  /* Initialise RGB LED */
  LED_RGB_Init();
  LED_RGB_SetIntensity(0, 0, 0);

  /* Initialise inertial measurement unit */
  BMI088_Init(&imu, &hspi1, GPIOA, SPI1_NCS_ACC_Pin, GPIOC, SPI1_NCS_GYR_Pin);

  /* Initialise barometric pressure sensor */
  SPL06_Init(&bar, &hspi3, GPIOA, SPI3_NCS_Pin);

  /* Initialise moving average filter for barometer */
  FIRFilter_Init(&barFilterMovingAverage);

  /* Initialise low-pass filters */
  for (uint8_t n = 0; n < 3; n++) {

	  RCFilter_Init(&lpfAcc[n], 5.0f, 0.01f);

	  RCFilter_Init(&lpfGyr[n], 25.0f, 0.01f);

  }

  /* Timers */
  uint32_t timerBAR = 0;
  uint32_t timerUSB = 0;
  uint32_t timerLED	= 0;
  uint32_t timerATT = 0;

  /* LED colour state */
  uint8_t ledState = 0;

  /* Roll and pitch estimates */
  rollEstimate_rad  = 0.0f;
  pitchEstimate_rad = 0.0f;

  /* USB data buffer */
  char logBuf[128];
  /* USER CODE END 2 */

  /* Infinite loop */
  /* USER CODE BEGIN WHILE */
  float rollAcc_rad  = 0.0f;
  float pitchAcc_rad = 0.0f;

  float rollGyr_rad = 0.0f;
  float pitchGyr_rad = 0.0f;

  while (1)
  {
    /* USER CODE END WHILE */

	  /* Log data via USB */
	  if ((HAL_GetTick() - timerUSB) >= SAMPLE_TIME_MS_USB) {

		  /* Print via USB */
		 // sprintf(logBuf, "%.1f,%.1f,%.1f,%.1f,%.1f,%.1f\r\n", rollEstimate_rad * RAD_TO_DEG, pitchEstimate_rad * RAD_TO_DEG,
		//		  	  	  	  	  	  	 	 	 	 rollAcc_rad * RAD_TO_DEG, pitchAcc_rad * RAD_TO_DEG,
		//											 rollGyr_rad * RAD_TO_DEG, pitchGyr_rad * RAD_TO_DEG);

		  sprintf(logBuf, "%.3f,%.3f,%.3f,%.3f,%.3f,%.3f\r\n", imu.acc_mps2[0], imu.acc_mps2[1], imu.acc_mps2[2],
				  	  	  	  	  	  	  	  	  	  	  	   imu.gyr_rps[0], imu.gyr_rps[1], imu.gyr_rps[2]);

		  CDC_Transmit_FS((uint8_t *) logBuf, strlen(logBuf));

		  timerUSB = HAL_GetTick();

	  }

	  /* Read pressure sensor */
	  if ((HAL_GetTick() - timerBAR) >= SAMPLE_TIME_MS_BAR) {

		  SPL06_ReadDMA(&bar);

		  timerBAR = HAL_GetTick();

	  }

	  /* Toggle LED */
	  if ((HAL_GetTick() - timerLED) >= SAMPLE_TIME_MS_LED) {

		  switch(ledState) {

			  case 0:
				  LED_RGB_SetIntensity(100, 0, 0);
				  break;

			  case 1:
				  LED_RGB_SetIntensity(0, 75, 0);
				  break;

			  case 2:
				  LED_RGB_SetIntensity(0, 0, 100);
				  break;

		  }

		  ledState++;

		  if (ledState > 2) {

			  ledState = 0;

		  }

		  timerLED = HAL_GetTick();

	  }

    /* USER CODE BEGIN 3 */
  }
  /* USER CODE END 3 */
}

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


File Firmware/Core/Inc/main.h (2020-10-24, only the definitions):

#define INT_ACC_Pin GPIO_PIN_2
#define INT_ACC_GPIO_Port GPIOC
#define INT_ACC_EXTI_IRQn EXTI2_IRQn
#define INT_GYR_Pin GPIO_PIN_3
#define INT_GYR_GPIO_Port GPIOC
#define INT_GYR_EXTI_IRQn EXTI3_IRQn
#define SPI1_NCS_ACC_Pin GPIO_PIN_4
#define SPI1_NCS_ACC_GPIO_Port GPIOA
#define SPI1_NCS_GYR_Pin GPIO_PIN_4
#define SPI1_NCS_GYR_GPIO_Port GPIOC
#define FLASH_NHOLD_Pin GPIO_PIN_6
#define FLASH_NHOLD_GPIO_Port GPIOC
#define FLASH_NWP_Pin GPIO_PIN_7
#define FLASH_NWP_GPIO_Port GPIOC
#define SPI3_NCS_Pin GPIO_PIN_15
#define SPI3_NCS_GPIO_Port GPIOA
#define LED_RED_Pin GPIO_PIN_4
#define LED_RED_GPIO_Port GPIOB
#define LED_GREEN_Pin GPIO_PIN_5
#define LED_GREEN_GPIO_Port GPIOB
#define LED_BLUE_Pin GPIO_PIN_6
#define LED_BLUE_GPIO_Port GPIOB

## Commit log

2020-10-24 Initial commit.
    [Connectors.sch, Little-Brain-BOM.csv, Little-Brain-Footprint-Positions.csv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]
2020-10-25 Updated firmware. Added schematic PDF.
    [Connectors.sch, MCU.sch, Power.sch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]
2020-10-25 DMA for SPI (BMI088).
2020-10-25 SPL06 pressure sensor driver.
2020-10-25 DMA for pressure sensor.
2020-11-08 Fixed bug, made DMA txBuf persistent.
    [BMI088.c]
2020-11-08 FreeRTOS DMA.
2020-11-11 Changed USB connector.
    [Connectors.sch, Little-Brain-BOM.csv, Little-Brain-Footprint-Positions.csv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]
2020-12-20 Added FIR filtering routines.
2021-09-11 Various filters (IIR), ADXL355 driver.

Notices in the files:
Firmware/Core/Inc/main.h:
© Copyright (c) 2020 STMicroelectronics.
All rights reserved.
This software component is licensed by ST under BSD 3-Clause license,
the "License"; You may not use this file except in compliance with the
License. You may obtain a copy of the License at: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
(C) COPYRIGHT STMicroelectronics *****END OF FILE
